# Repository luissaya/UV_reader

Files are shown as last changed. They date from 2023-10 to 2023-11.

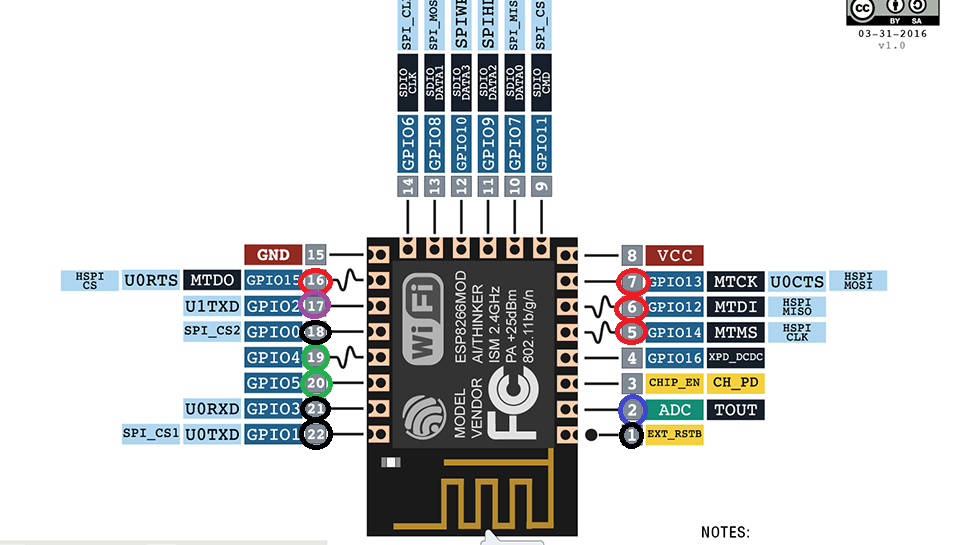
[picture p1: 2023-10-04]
img/pinout-esp8266.png

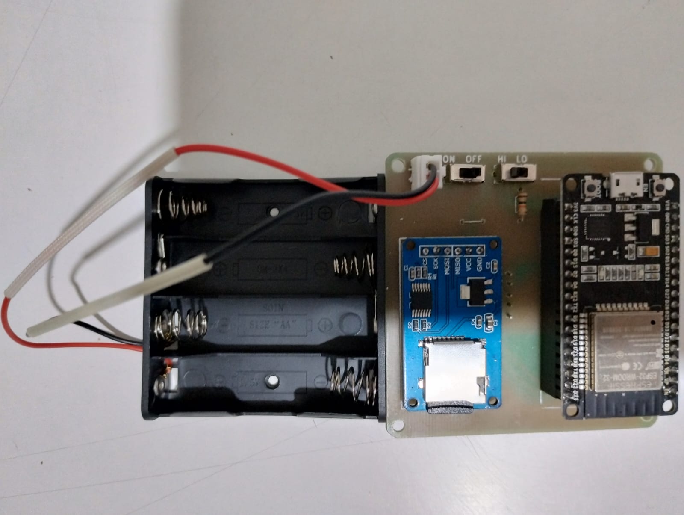
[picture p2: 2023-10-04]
img/pcb_front_view.jpg

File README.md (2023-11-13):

# UV reader

Read UV-A and UV-B radiation each minute and save the values with timestamp on an micro SD card.

## Pins

| Pin # | Name | Pin name | Description |
| ----- | --- | --- | --- |
| 1 | RST | - | Reset the chip |
| 2 | ADC | A0 | Read the UV sensor |
| 3 | RESET | - | Enable, must be HIGH |
| 4 | Deepsleep | 16 | Deepsleep, connect to RST pin |
| 5 | CSK | 14 | SPI pin |
| 6 | MISO | 12 | SPI pin |
| 7 | MOSI | 13 | SPI pin |
| 16 | CS | 15 | SPI pin |
| 17 | LED | 2 | LED, turn on in LOW |
| 18 | BOOT | 0 | To flash the firmware |
| 19 | SDA | 4 | I2C pin |
| 20 | SCL | 5 | I2C pin |
| 21 | RX | - | UART pin |
| 22 | TX | - | UART pin |
  
| Label | GPIO | Input | Output | Notes |
| ----- | --- | --- | --- | --- |
| D0 | GPIO16 | no interrupt  | no PWM or I2C support | HIGH at boot used to wake up from deep sleep |
| D1 | GPIO5  | OK | OK | often used as SCL (I2C) |
| D2 | GPIO4  | OK | OK | often used as SDA (I2C) |
| D3 | GPIO0  | pulled up | OK | connected to FLASH button, boot fails if pulled LOW |
| D4 | GPIO2  | pulled up | OK | HIGH at bootconnected to on-board LED, boot fails if pulled LOW |
| D5 | GPIO14 | OK | OK | SPI (SCLK) |
| D6 | GPIO12 | OK | OK | SPI (MISO) |
| D7 | GPIO13 | OK | OK | SPI (MOSI) |
| D8 | GPIO15 | pulled to GND | OK | SPI (CS), Boot fails if pulled HIGH |
| RX | GPIO3  | OK | RX pin | HIGH at boot |
| TX | GPIO1  | TX pin | OK | HIGH at boot, debug output at boot, boot fails if pulled LOW |
| A0 | ADC0 | Analog | Input | X |

## Calibration

Calculus to obtain the reference voltaje for genering UV intensity:

- `Vref` is the reference value to obtain:
- `Vout`: is read with multimeter.
- `Nread`: is read with ADC.

```bash
Vref = Vout x 1023 / Nread
Vref = 3.684
```

In the main code, put the next expression:  

```bash
Vout = Vref x Nread / 1023
Vout = 3.684 x Nread / 1023
```

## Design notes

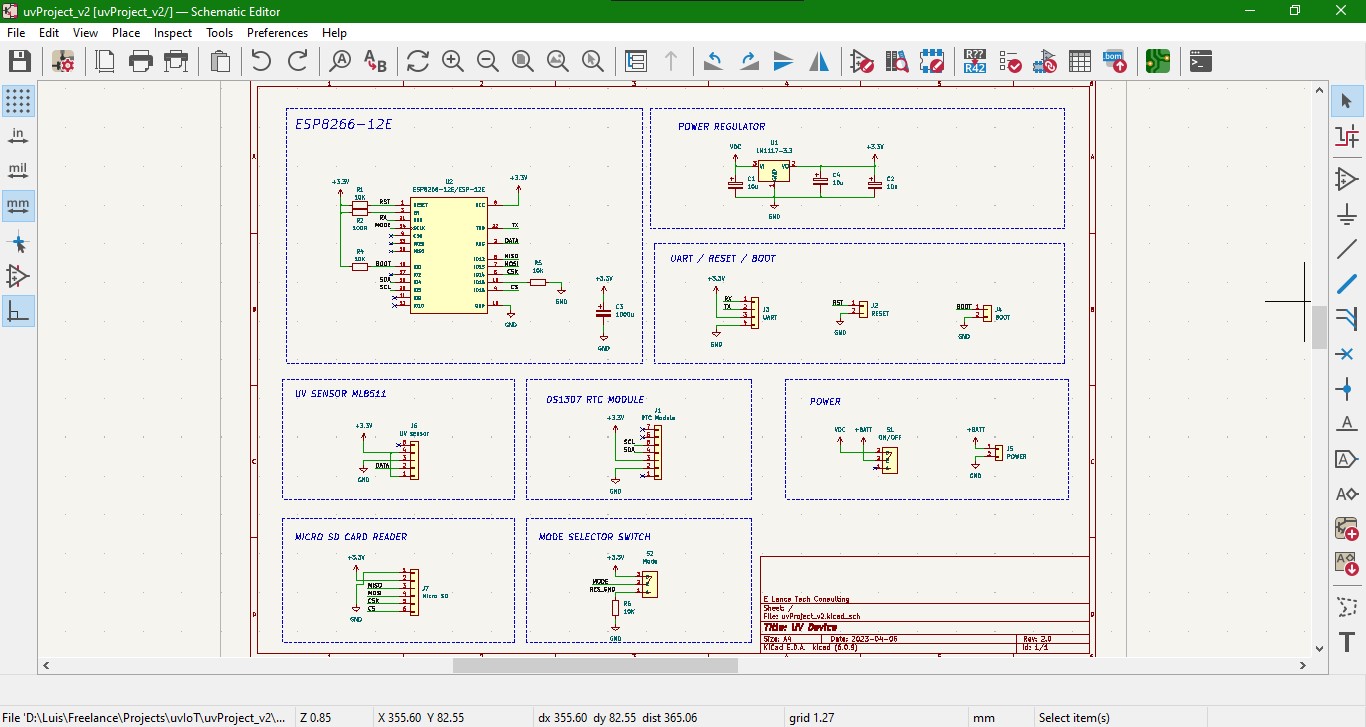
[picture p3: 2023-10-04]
img/schematic.jpg

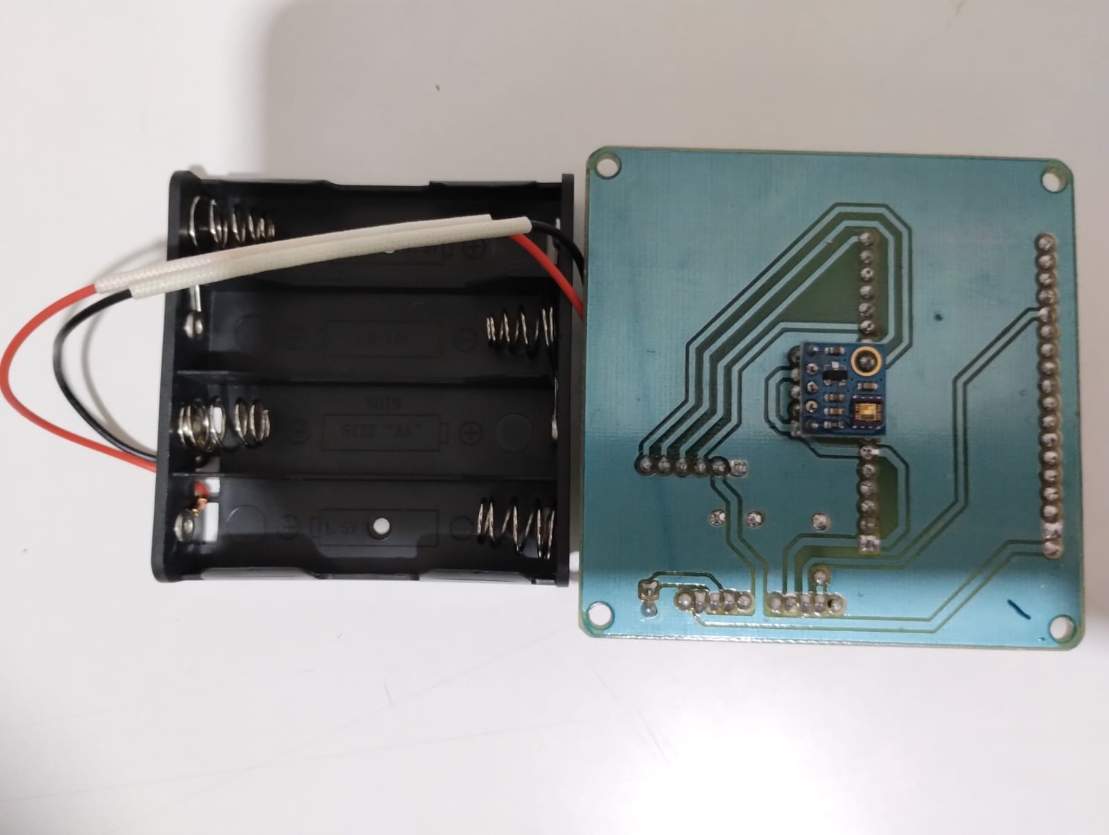
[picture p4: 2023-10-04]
img/pcb_back_view.jpg

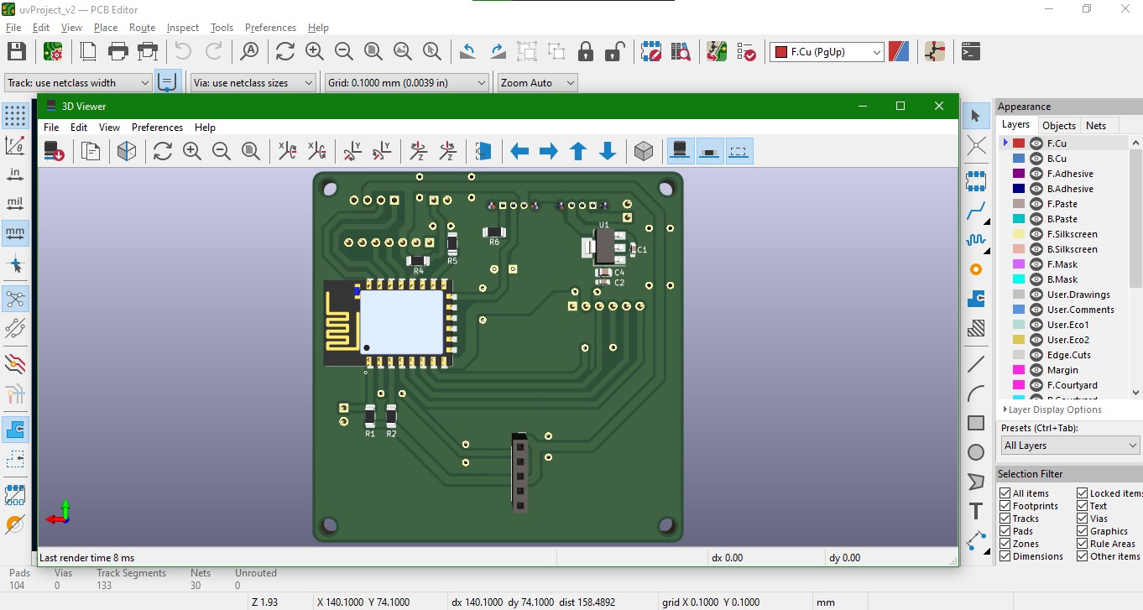
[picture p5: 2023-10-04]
img/layout.jpg

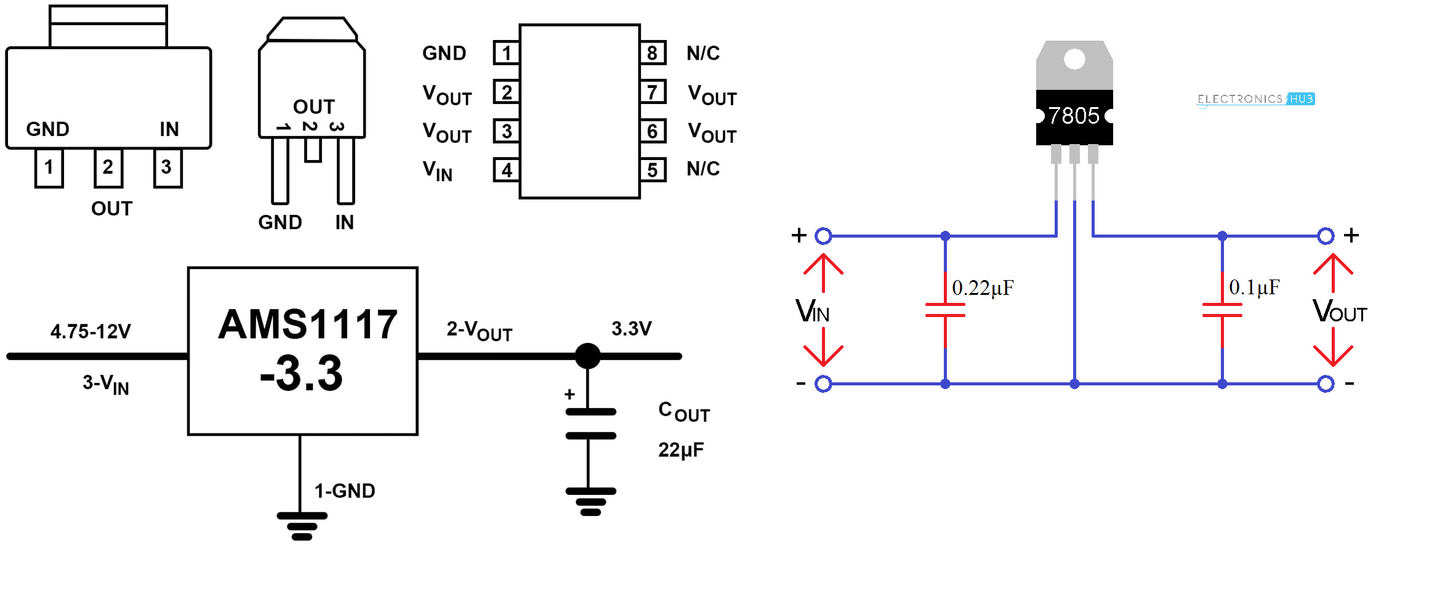
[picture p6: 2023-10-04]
pcb/uvProject_v2/crcuit.png

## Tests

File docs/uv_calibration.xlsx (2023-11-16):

Vmultimeter(volts) | Nread | Resolution | Vref(volts)
1.05 | 292 | 1023 | 3.67859589

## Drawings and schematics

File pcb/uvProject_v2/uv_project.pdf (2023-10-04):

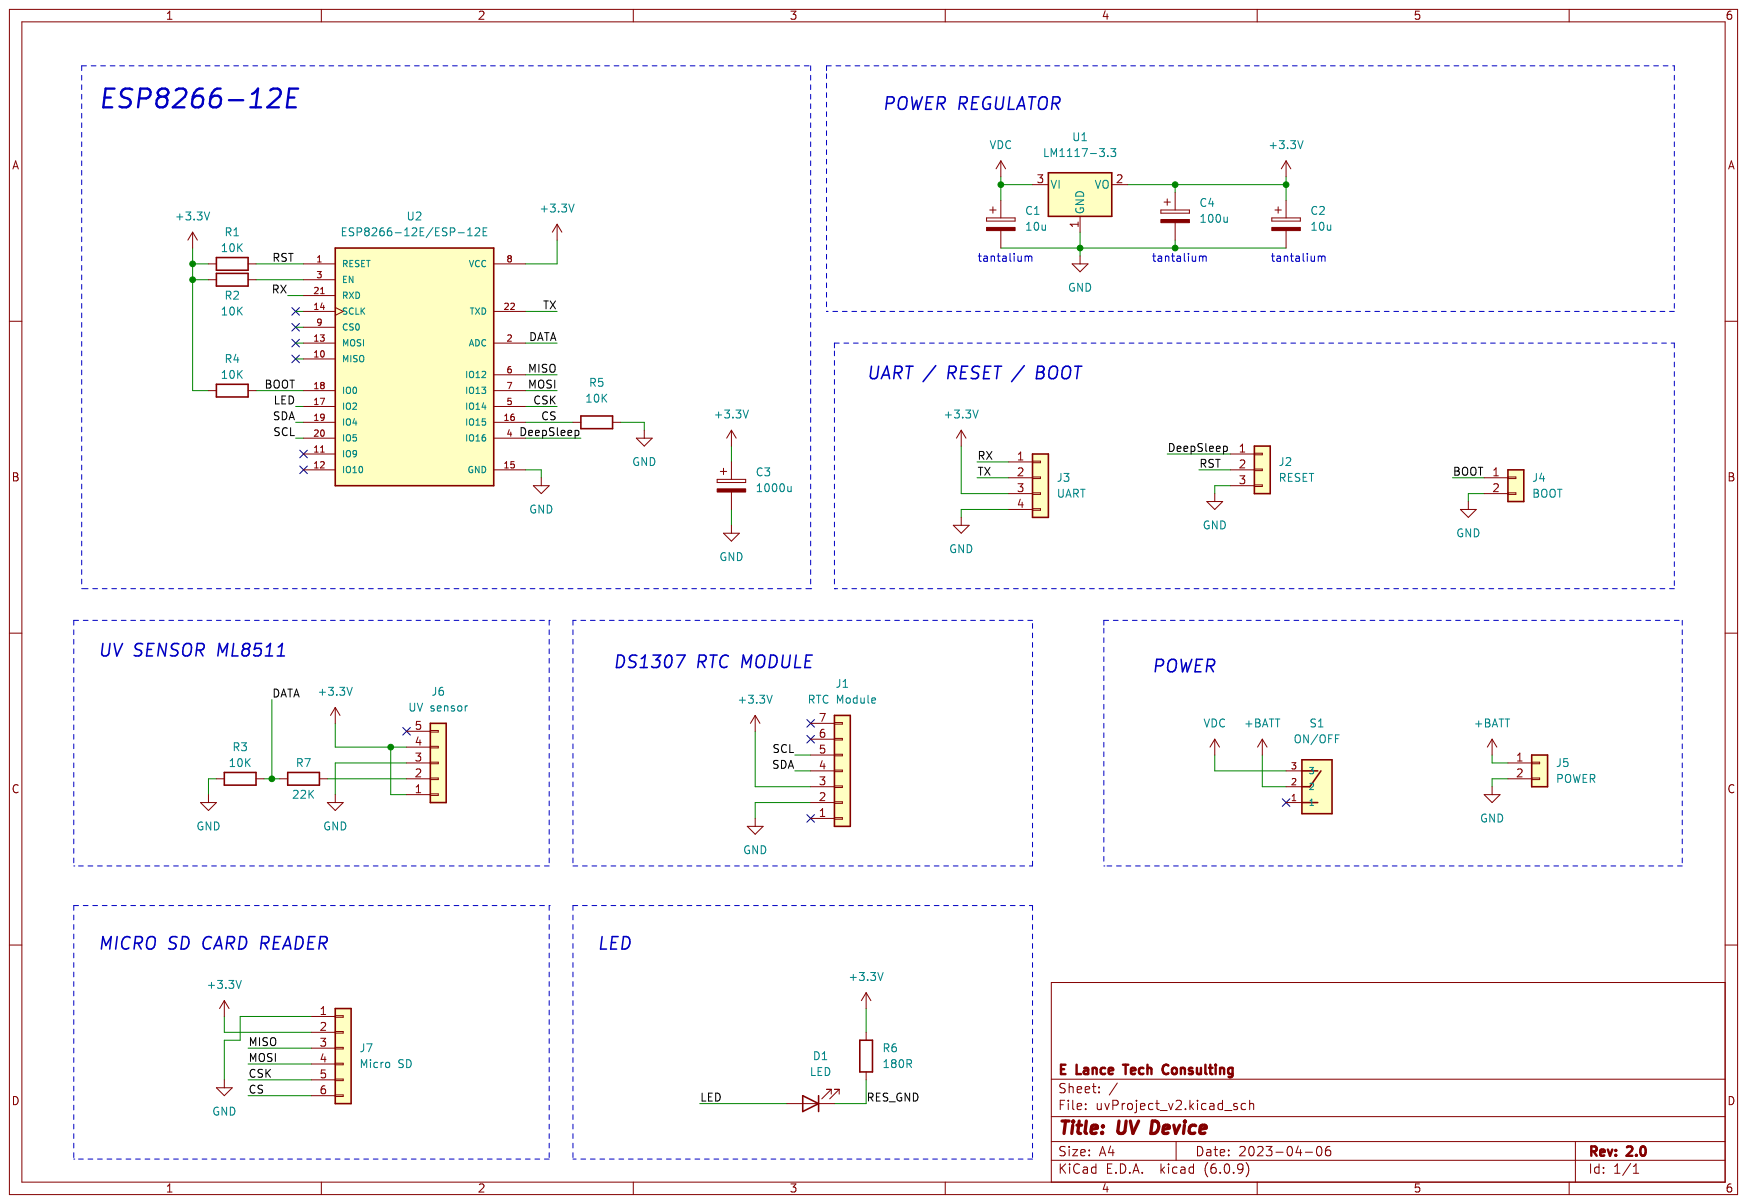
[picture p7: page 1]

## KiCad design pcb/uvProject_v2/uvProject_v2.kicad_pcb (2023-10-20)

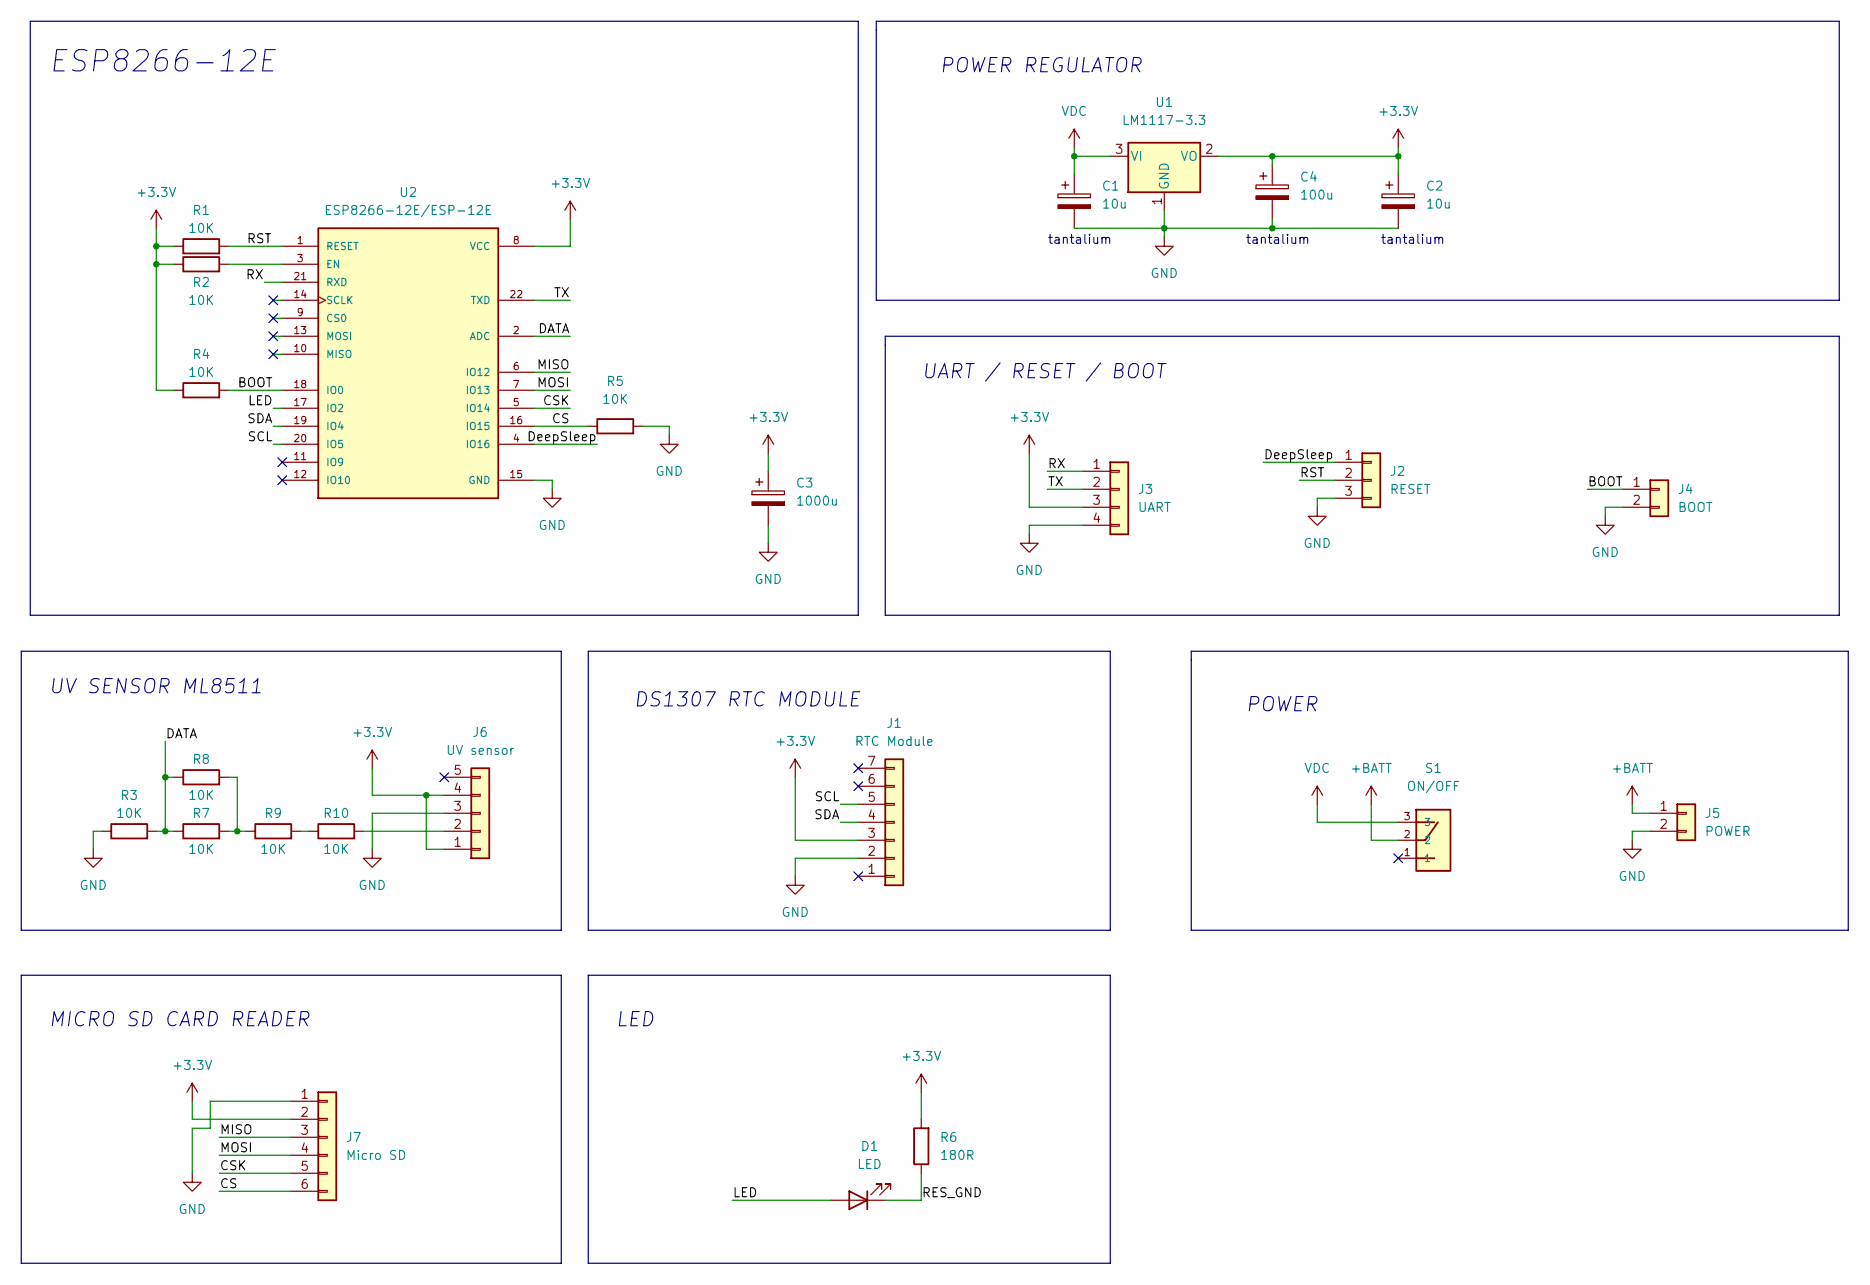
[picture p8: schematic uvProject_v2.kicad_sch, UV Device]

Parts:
C1, C2: 10u; C_0603_1608Metric_Pad1.08x0.95mm_HandSolder
C3: 1000u; CP_Radial_D8.0mm_P3.50mm
C4: 100u; C_0805_2012Metric_Pad1.18x1.45mm_HandSolder
D1: LED; LED_D3.0mm
J1: RTC Module; PinHeader_1x07_P2.54mm_Vertical
J2: RESET; PinHeader_1x03_P2.54mm_Vertical
J3: UART; PinSocket_1x04_P2.54mm_Vertical
J4: BOOT; PinHeader_1x02_P2.54mm_Vertical
J5: POWER; PinHeader_1x02_P2.54mm_Vertical
J6: UV sensor; PinSocket_1x05_P2.54mm_Vertical
J7: Micro SD; PinHeader_1x06_P2.54mm_Vertical
R1, R2, R3, R4, R5, R7, R8, R9, R10: 10K; R_1206_3216Metric_Pad1.30x1.75mm_HandSolder
R6: 180R; R_1206_3216Metric_Pad1.30x1.75mm_HandSolder
S1: ON/OFF; SW_OS102011MS2QN1
U1: LM1117-3.3; SOT-223-3_TabPin2
U2: ESP8266-12E/ESP-12E; XCVR_ESP8266-12E_ESP-12E

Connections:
+3.3V: C2.1, C3.1, C4.1, J1.3, J3.3, J6.1, J6.4, J7.2, R1.1, R2.1, R4.1, R6.2, U1.2 (VO), U2.8 (VCC)
+BATT: J5.1, S1.2
/BOOT: J4.1, R4.2, U2.18 (IO0)
/CS: J7.6, R5.1, U2.16 (IO15)
/CSK: J7.5, U2.5 (IO14)
/DATA: R3.2, R7.1, R8.1, U2.2 (ADC)
/DeepSleep: J2.1, U2.4 (IO16)
/LED: D1.2 (A), U2.17 (IO2)
/MISO: J7.3, U2.6 (IO12)
/MOSI: J7.4, U2.7 (IO13)
/RES_GND: D1.1 (K), R6.1
/RST: J2.2, R1.2, U2.1 (RESET)
/RX: J3.1, U2.21 (RXD)
/SCL: J1.5, U2.20 (IO5)
/SDA: J1.4, U2.19 (IO4)
/TX: J3.2, U2.22 (TXD)
GND: C1.2, C2.2, C3.2, C4.2, J1.2, J2.3, J3.4, J4.2, J5.2, J6.3, J7.1, R3.1, R5.2, U1.1 (GND), U2.15 (GND)
unnamed: J6.2, R10.2
unnamed: R7.2, R8.2, R9.1
unnamed: R9.2, R10.1
unnamed: R2.2, U2.3 (EN)
VDC: C1.1, S1.3, U1.3 (VI)

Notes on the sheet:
tantalium
UV SENSOR ML8511
ESP8266-12E
POWER
MICRO SD CARD READER
DS1307 RTC MODULE
LED
UART / RESET / BOOT
POWER REGULATOR

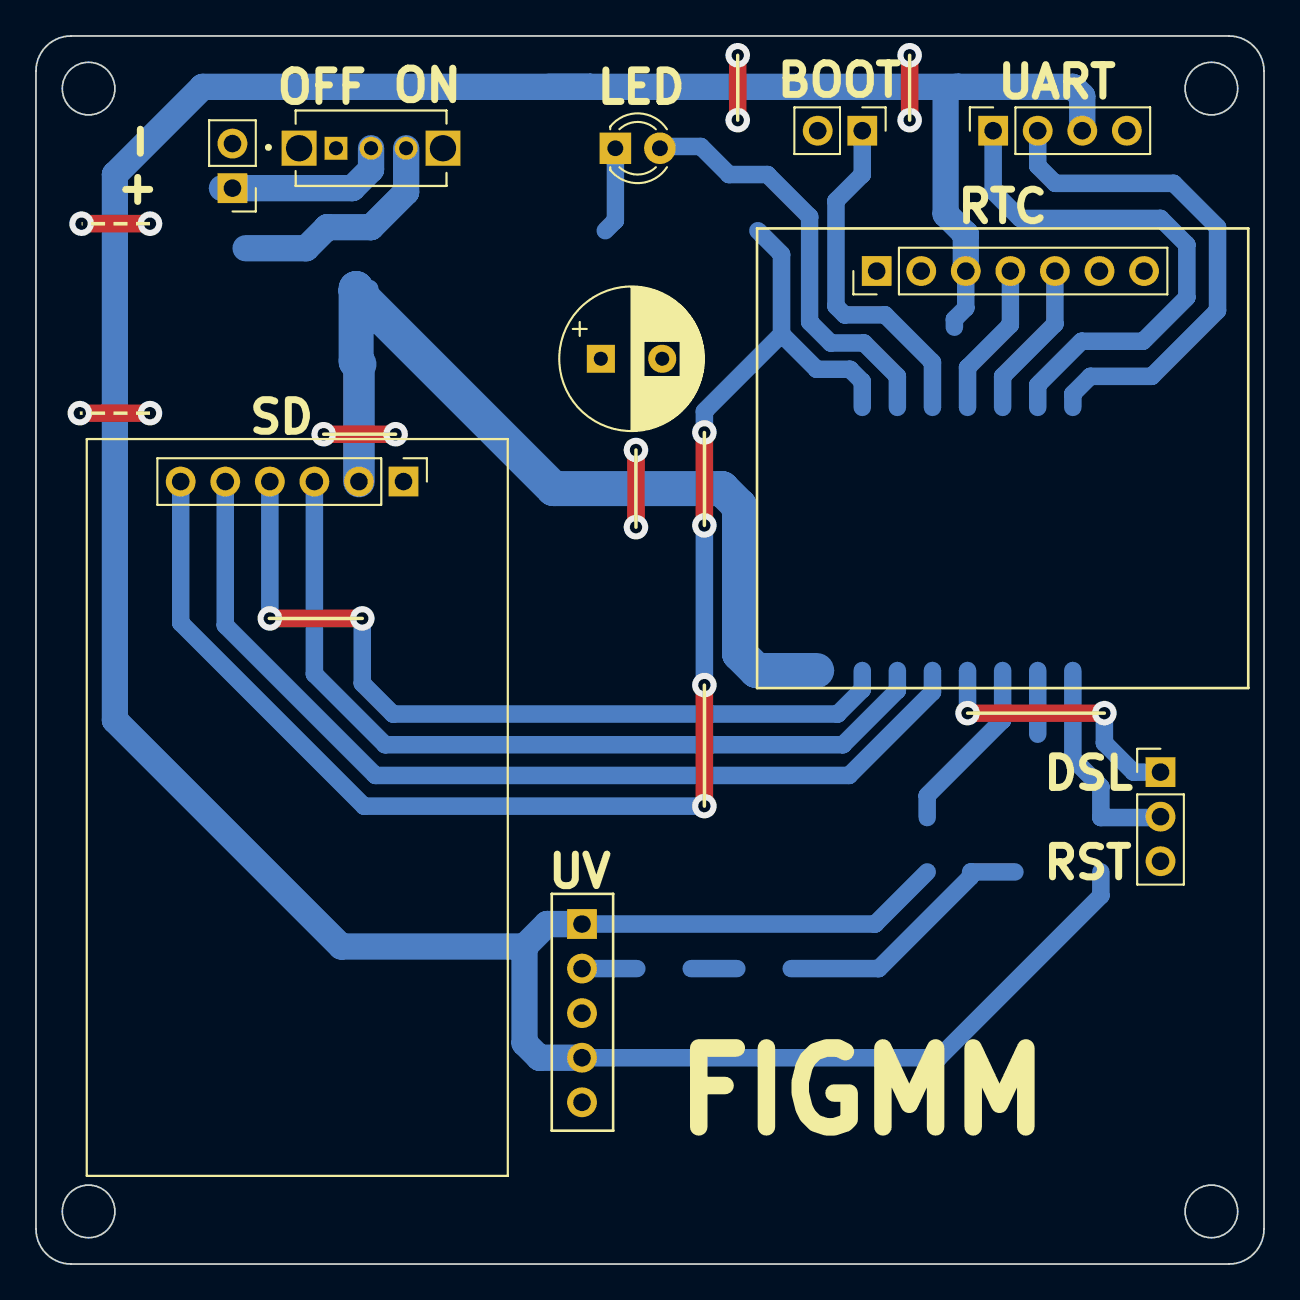
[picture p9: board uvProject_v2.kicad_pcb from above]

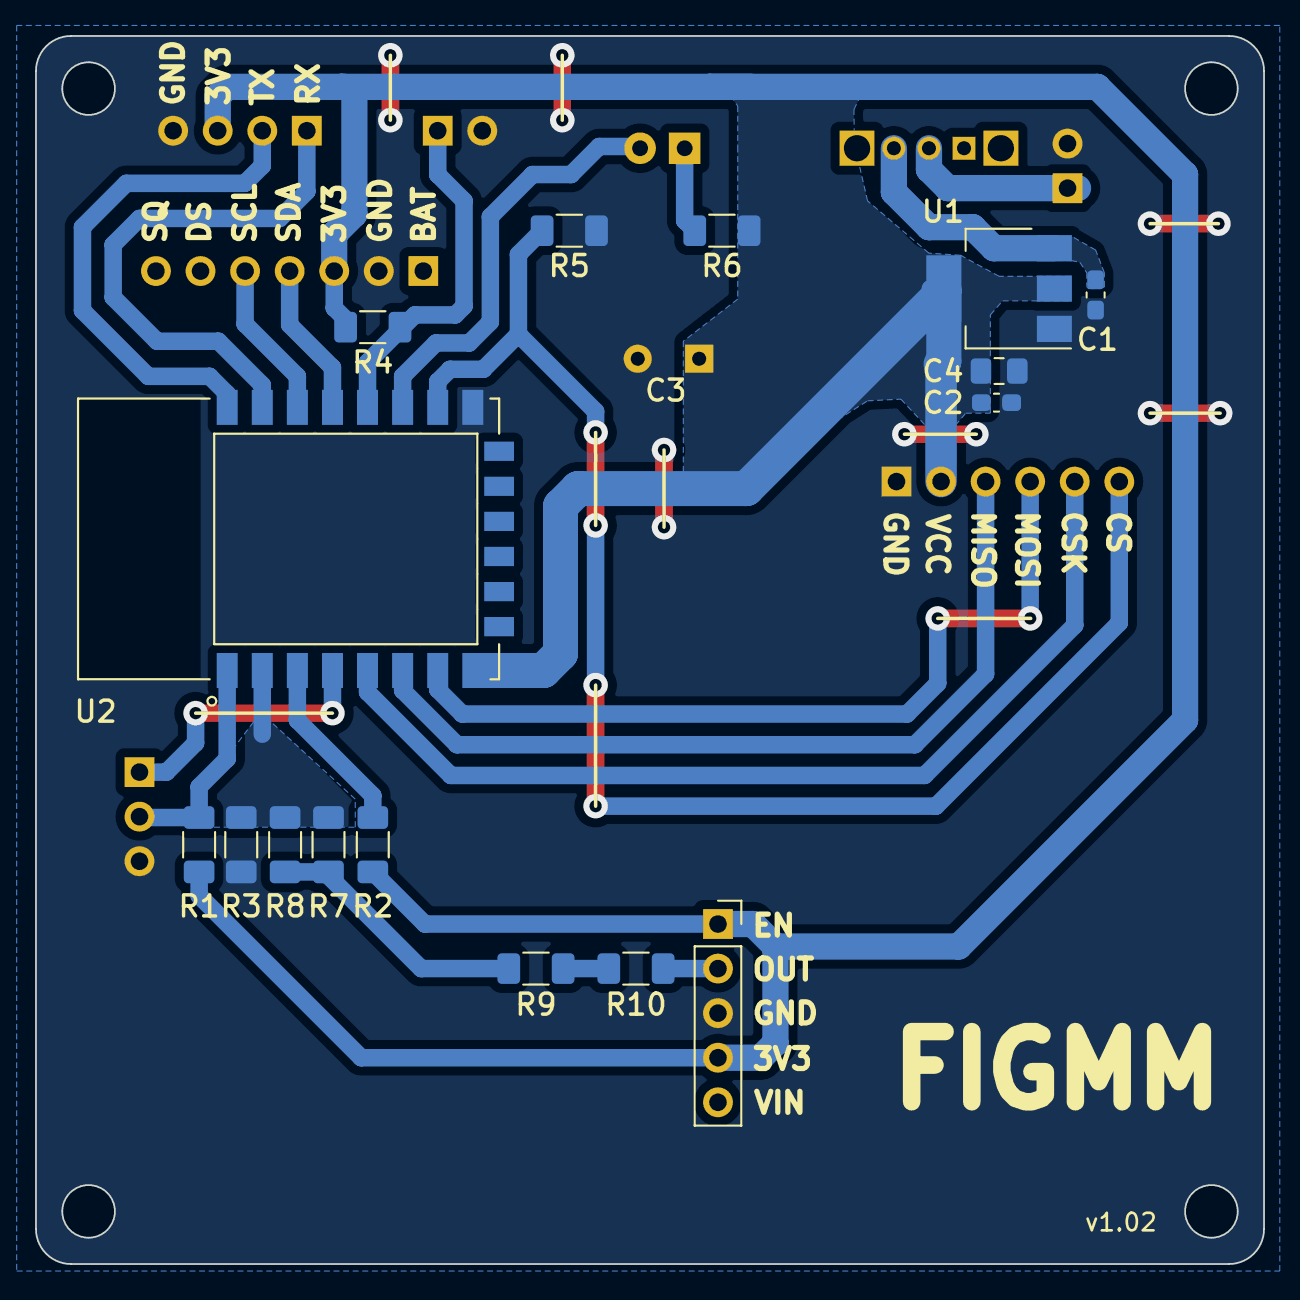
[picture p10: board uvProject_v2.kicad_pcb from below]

Board: 2 copper layers, 70.0 x 70.0 mm, 25 parts (16 on the bottom side), 22 nets.

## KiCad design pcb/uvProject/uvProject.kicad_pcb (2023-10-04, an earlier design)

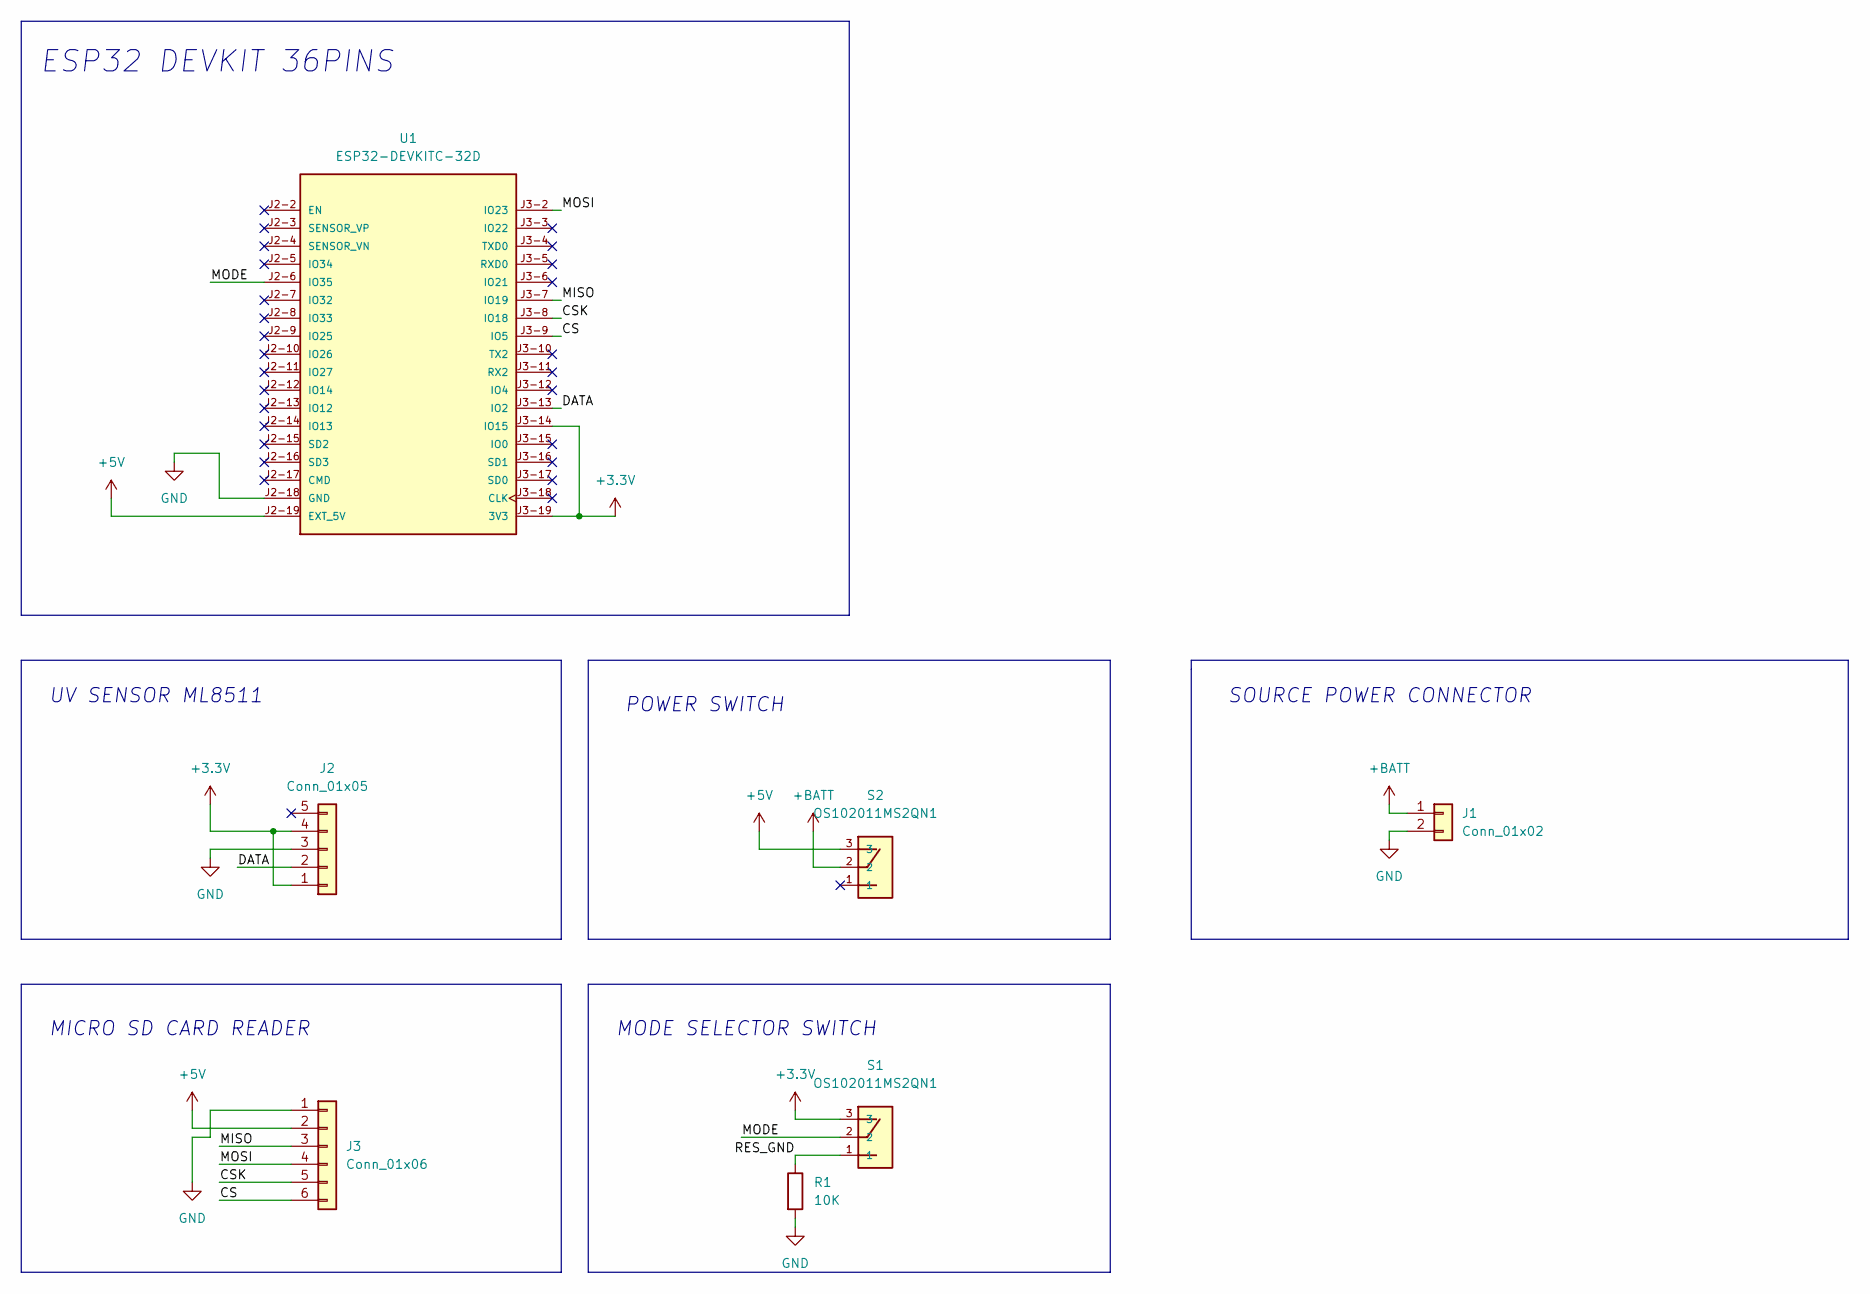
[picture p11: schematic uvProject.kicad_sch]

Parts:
J1: Conn_01x02; PinHeader_1x02_P2.54mm_Vertical
J2: Conn_01x05; PinSocket_1x05_P2.54mm_Vertical
J3: Conn_01x06; PinSocket_1x06_P2.54mm_Vertical
R1: 10K; R_Axial_DIN0204_L3.6mm_D1.6mm_P7.62mm_Horizontal
S1, S2: OS102011MS2QN1; SW_OS102011MS2QN1
U1: ESP32-DEVKITC-32D; MODULE_ESP32-DEVKITC-32D; PARTREV V4

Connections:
+3.3V: J2.1, J2.4, S1.3, U1.J3-14 (IO15), U1.J3-19 (3V3)
+5V: J3.2, S2.3, U1.J2-19 (EXT_5V)
+BATT: J1.1, S2.2
/CS: J3.6, U1.J3-9 (IO5)
/CSK: J3.5, U1.J3-8 (IO18)
/DATA: J2.2, U1.J3-13 (IO2)
/MISO: J3.3, U1.J3-7 (IO19)
/MODE: S1.2, U1.J2-6 (IO35)
/MOSI: J3.4, U1.J3-2 (IO23)
/RES_GND: R1.1, S1.1
GND: J1.2, J2.3, J3.1, R1.2, U1.J2-18 (GND)

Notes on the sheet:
ESP32 DEVKIT 36PINS
MODE SELECTOR SWITCH
POWER SWITCH
SOURCE POWER CONNECTOR
UV SENSOR ML8511
MICRO SD CARD READER

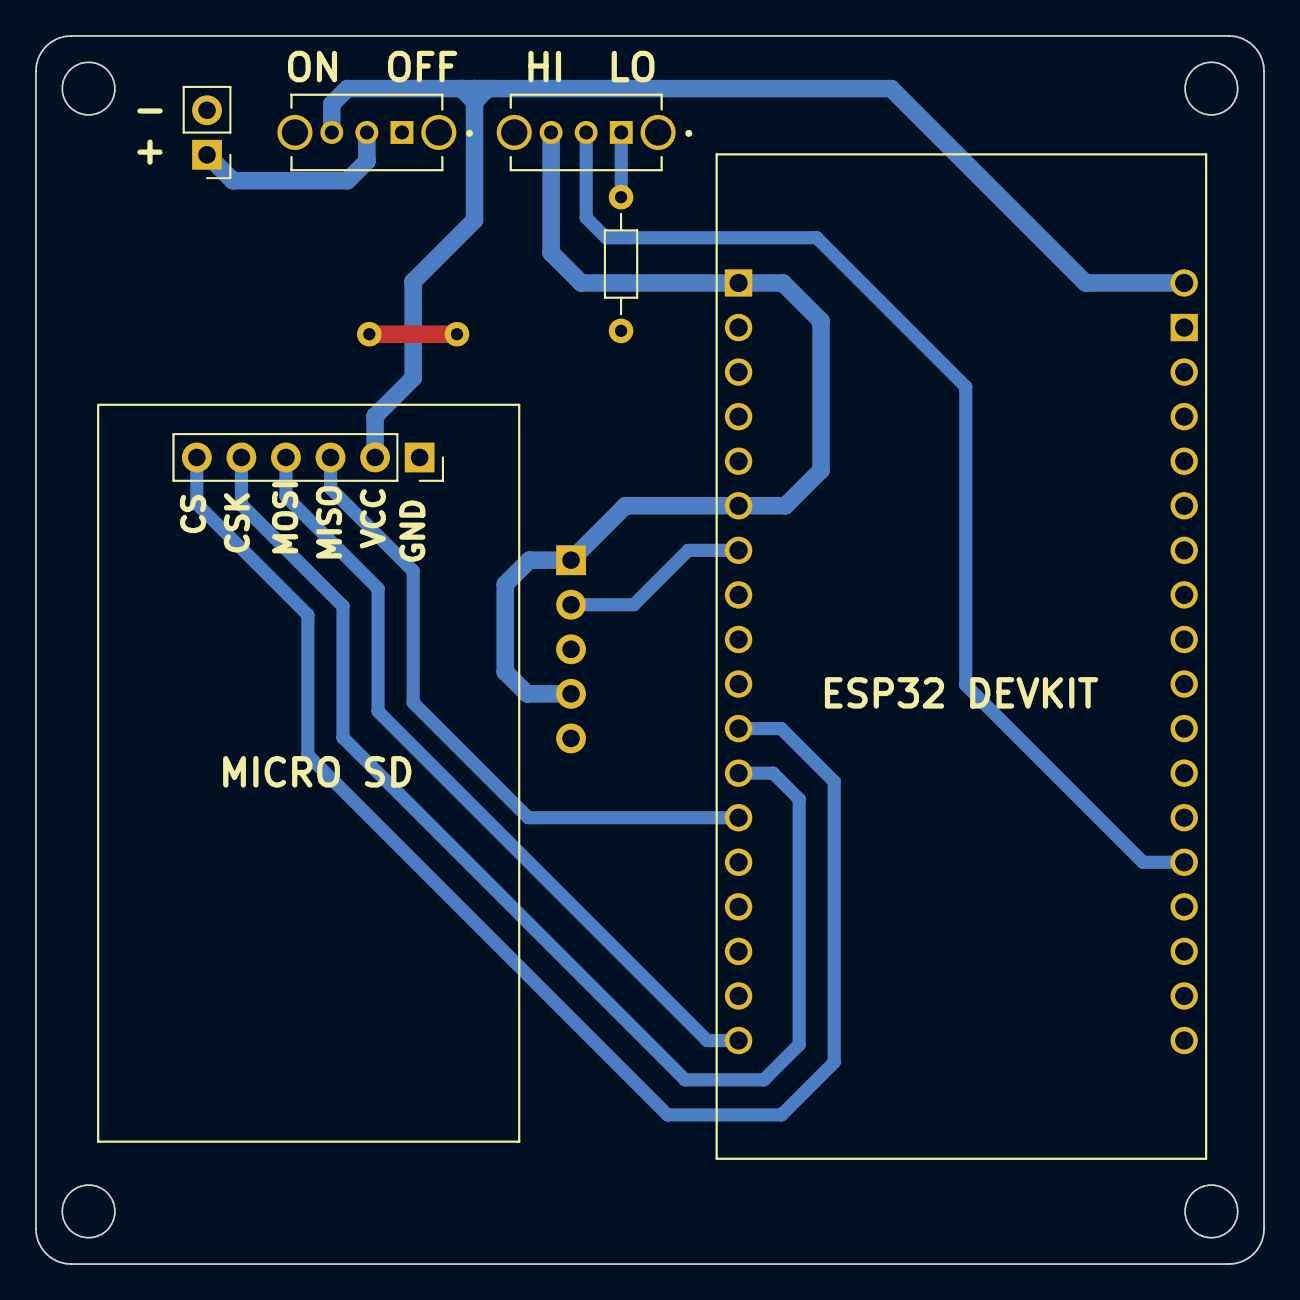
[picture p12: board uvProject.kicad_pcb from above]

Board: 2 copper layers, 70.0 x 70.0 mm, 7 parts (1 on the bottom side), 11 nets.

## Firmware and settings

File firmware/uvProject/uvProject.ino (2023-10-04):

#include "FS.h"
#include "SD.h"
#include "SPI.h"

#define SCK  18
#define MISO 19
#define MOSI 23
#define CS    5
#define UVOUT 2 //Output from the sensor
#define REF  15 //3.3V power on the ESP32 board
#define MODE 35 //Output from the operation mode

#define uS_TO_S_FACTOR 1000000  /* Conversion factor for micro seconds to seconds */
#define Sleep_Interval 10000 //10 seconds
#define time_HI 30
#define time_LO 60
#define led 2
/* create a hardware timer */
hw_timer_t * timer = NULL;
unsigned long previousMillis = 0; 

String nameFILE = "/uvData.csv"; // .csv file
float uvLevel = 0.0;
float refLevel = 0.0;
bool existName = false;
bool debug = false;
int TIME_TO_SLEEP = time_LO;        /* Time ESP32 will go to sleep (in seconds) */
int modeValue = 0;
RTC_DATA_ATTR int bootCount = 0;


void averageRead(int numberReadings);
float voltageToIntensity(float voltage);
void writeFile(fs::FS &fs, String name, String message);
void addData(fs::FS &fs, String name, float message);
void createFileTitle(fs::FS &fs, String name, String message);

SPIClass sdspi(VSPI);

volatile byte state = LOW;

void IRAM_ATTR onTimer(){
  state = !state;
  digitalWrite(led, state);
}

void setup(){
  if(debug) Serial.begin(115200);
  if(debug) delay(2000);    
  if(debug) Serial.println("Initializing");  
  pinMode(UVOUT, INPUT);
  pinMode(REF, INPUT);  
  pinMode(MODE, INPUT);
  pinMode(led, OUTPUT);

  modeValue = digitalRead(MODE);
  delay(50);
  if(modeValue == HIGH){
    TIME_TO_SLEEP = time_HI; // HIGH or LOW,  less time if it is activated
  }

  /* Use 1st timer of 4 */
  /* 1 tick take 1/(80MHZ/80) = 1us so we set divider 80 and count up */
  timer = timerBegin(0, 80, true);
  /* Attach onTimer function to our timer */
  timerAttachInterrupt(timer, &onTimer, true);
  /* Set alarm to call onTimer function every second 1 tick is 1us
  => 1 second is 1000000us */
  /* Repeat the alarm (third parameter) */
  timerAlarmWrite(timer, 0.2*uS_TO_S_FACTOR, true);
  timerAlarmEnable(timer);

  //boot count
  ++bootCount;
  if(debug) Serial.println("Boot number: " + String(bootCount));

  sdspi.begin(SCK, MISO, MOSI, CS);

  while(!SD.begin(CS,sdspi)){
    if(debug) Serial.println("Card Mount Failed");
    unsigned long currentMillis = millis();
    Serial.println(currentMillis);
    if (currentMillis >= Sleep_Interval) {
      if(debug) Serial.println("Setup ESP32 to sleep for every indefinitely");
      //esp_sleep_enable_timer_wakeup(120*uS_TO_S_FACTOR);
      esp_sleep_enable_touchpad_wakeup();
      esp_deep_sleep_start();
    }
  }
  if(debug) Serial.println("Card Mount successfully");
  uint8_t cardType = SD.cardType();

  while(cardType == CARD_NONE){
    if(debug) Serial.println("No SD card attached");
    unsigned long currentMillis = millis();
    if (currentMillis - previousMillis >= Sleep_Interval) {
      if(debug) Serial.println("Setup ESP32 to sleep for every indefinitely");
      //esp_sleep_enable_timer_wakeup(120*uS_TO_S_FACTOR);
      esp_sleep_enable_touchpad_wakeup();
      esp_deep_sleep_start();
    }
    delay(500);
  }
  if(debug) Serial.println("SD card attached successfully");

  // if(!SD.begin(CS,sdspi)){
  //   if(debug) Serial.println("Card Mount Failed");
  //   return;
  // }
  // uint8_t cardType = SD.cardType();
  // if(cardType == CARD_NONE){
  //   if(debug) Serial.println("No SD card attached");
  //   return;
  // }
  if(bootCount == 1){
    createFileTitle(SD,nameFILE, "Time, UV Intensity (mW/cm^2)\n");
    delay(1000);
  }
  timerAlarmDisable(timer);
  digitalWrite(led, LOW);

  float uvIntensity = voltageToIntensity(averageVoltage(20)); //Convert the voltage to a UV intensity level
  String timepass = timeElapsed(bootCount-1);
  if(debug) Serial.println(timepass);
  addData(SD, nameFILE, timepass + ", " + String(uvIntensity));
  //go to sleep
  esp_sleep_enable_timer_wakeup(TIME_TO_SLEEP * uS_TO_S_FACTOR);
  if(debug) Serial.println("Setup ESP32 to sleep for every " + String(TIME_TO_SLEEP) +" Seconds");
  if(debug) Serial.print("ESP is going to sleep");
  Serial.flush(); 
  esp_deep_sleep_start();
}

void loop(){
  //This is not going to be called
}

float averageVoltage(int numberReadings){ 
  for(int x = 0 ; x < numberReadings ; x++)
  {
    uvLevel += analogRead(UVOUT);
    refLevel += analogRead(REF);
  }
  uvLevel /= (float)numberReadings;
  refLevel /= (float)numberReadings;
  //Use the 3.3V power pin as a reference to get a very accurate output value from sensor
  return (3.3 / refLevel * uvLevel);
}

float voltageToIntensity(float voltage){
  float in_min = 0.99;
  float in_max = 2.8;
  float out_min = 0.0;
  float out_max = 15.0;
  if (voltage <= in_min){
    return out_min;
  }
  return (voltage - in_min) * (out_max - out_min) / (in_max - in_min) + out_min;
}

void addData(fs::FS &fs, String name, String message){
 if(debug) Serial.print("Appending to file: "+ name);

  File file = fs.open(name, FILE_APPEND);
  if(!file){
    if(debug) Serial.println(" Failed to open file for appending");
    return;
  }
  if(file.println(message)){
     if(debug) Serial.println(" Message appended");
  } else {
    if(debug) Serial.println(" Append failed");
  }
  file.close();
}

void createFileTitle(fs::FS &fs, String name, String message){
 if(debug) Serial.print("Appending to file: "+ name);

  File file = fs.open(name, FILE_APPEND);
  if(!file){
    if(debug) Serial.println(" Failed to open file for appending");
    return;
  }
  if(file.print(message)){
    if(debug) Serial.println(" Title appended");
  } else {
    if(debug) Serial.println(" Append failed");
  }
  file.close();
}

String timeElapsed(int boot){
  String timeDHM;
  int timeD = boot/3600;
  int timeH = (boot - timeD*3600)/60 ;
  int timeM = boot - timeD*3600 - timeH*60;
  String sTimeD;
  String sTimeH;
  String sTimeM;
  if (timeD<10){
      sTimeD = "0"+String(timeH);
    }else {
      sTimeD = String(timeH);
    }
   if (timeH<10){
      sTimeH = "0"+String(timeH);
    }else {
      sTimeH = String(timeH);
    }
   if (timeM<10){
      sTimeM = "0"+String(timeM);
    }else {
      sTimeM = String(timeM);
    }
  timeDHM = sTimeD+"D:"+sTimeH+"H:"+sTimeM+"M";
  return timeDHM;
}

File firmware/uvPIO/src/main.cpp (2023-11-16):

/*
Repository: https://github.com/luissaya/UV_reader
Project: UV radiation data collector
Author: Luis Sayaverde Bravo
v1.04
*/
#include <SPI.h>
#include <SD.h>
#include <Ticker.h>
#include "RTClib.h"
/*
ESP12E 
- I2C:  SDA=GPIO4, 
        SCL=GPIO5
- SPI:  MISO=GPIO12, 
        MOSI=GPIO13, 
        CSK=GPIO14 
        CS=GPIO15 <> D8
- LED:  GPIO2 <> D4
- ADC:  A0
*/

// CONSTANTS //
#define CS  D8 //GPIO15 D8 
#define LED D4 //GPIO2 D4
#define UV  A0 // A0
#define sleep_waiting 10e3 //time for sleep indefinitely if there is an error
#define sleep_time 60e6 //time for take each measurement
bool debug = false; //true to activate debug prints
String title = "uvData.csv";//csv file name
String fileHeader = "Fecha(DD/MM/AAAA), Hora(HH:MM:SS), UV Intensity(mW/cm^2)";//header of csv file
float RES = 1023.0;//ADC resolution
float REF = 3.684;//variable obtained through calibration

// VARIABLES //
unsigned long previousMillis = 0; 
String message = "";
float uvIntensity = 0.0;

// INSTANCES //
File myFile;
Ticker blinker;
RTC_DS1307 rtc;

// FUNCTION PROTOTYPES //
void changeState();
float avgVoltage(int nReadings);
float voltToIntensity(float voltage);
void writingSD(String message, String file);
void readingSD(String file);
void printDirectory();
String currentTime();
String addZero(int number);

// MAIN SETUP //
void setup() {
  // Open serial communications and wait for port to open:
  if(debug) Serial.begin(9600);
  pinMode(LED,OUTPUT);
  pinMode(UV, INPUT);
  if(debug) delay(1000);
  if(debug) Serial.println("Initializing");
  blinker.attach(0.2, changeState); //Initialize Ticker every 0.5s (Use attach_ms for time in ms)
  
  while (! rtc.begin()) {
    if(debug) Serial.println("Couldn't find RTC");
    if(debug) Serial.flush();
    // ADD SLEEP
    unsigned long currentMillis = millis();
    if (currentMillis >= sleep_waiting) {
      if(debug) Serial.println("Setup to sleep for every indefinitely");
      if(debug) Serial.flush();
      ESP.deepSleep(0); 
    }
  }
  if (!rtc.isrunning()) {
    if(debug) Serial.println("RTC is NOT running, let's set the time!");
    rtc.adjust(DateTime(F(__DATE__), F(__TIME__)));
  }
/////////////////////////////////////////////////////
// rtc.adjust(DateTime(F(__DATE__), F(__TIME__)));//set the time with the compiled one
////////////////////////////////////////////////////
// rtc.adjust(DateTime(2023, 4, 9, 11, 47, 0));
  
  if(debug) Serial.print("Initializing SD card...");
  while (!SD.begin(CS)) {
    if(debug) Serial.println("initialization failed!");
    // ADD SLEEP
    unsigned long currentMillis = millis();
    if (currentMillis >= sleep_waiting) {
      if(debug) Serial.println("Setup to sleep for every indefinitely");
      if(debug) Serial.flush();
      ESP.deepSleep(0);
    }
    delay(1000);
  }
  if(debug) Serial.println("initialization done.");
  
  blinker.detach(); 
  digitalWrite(LED,HIGH);

  if (!SD.exists(title)) {
    if(debug) Serial.println(title + " doesn't exist");
    if(debug) Serial.println("File Header : " + fileHeader);
    writingSD(fileHeader, title);
  }
  if(debug) Serial.println(title + " exists");
  //Convert the voltage to a UV intensity level
  uvIntensity = voltToIntensity(avgVoltage(20));
  message = currentTime() +", "+ String(uvIntensity);
  writingSD(message, title);
  // if(debug) readingSD(title);
  if(debug) Serial.println(message);

  if(debug) Serial.println("I'm awake, but I'm going into deep sleep mode for 60 seconds");
  if(debug) Serial.flush();
  ESP.deepSleep(sleep_time);
}

// MAIN LOOP //
void loop() {
  
}

// BLINK FOR LED //
void changeState(){
  digitalWrite(LED, !(digitalRead(LED)));  //Invert Current State of LED  
}

// GET AVERAGE VOLTAGE OF UV //
float avgVoltage(int nReadings){ 
  int uvLevel = 0;
  for(int x = 0 ; x < nReadings ; x++)
  {
    uvLevel += analogRead(UV);
  }
  uvLevel /= (float)nReadings;
  //Use the 3.3V power pin as a reference to get a very accurate output value from sensor
  return (REF / RES * uvLevel);
}

// CONVERT VOLTAGE OF UV TO UV INTENSITY //
float voltToIntensity(float voltage){
  float in_min = 0.99;
  float in_max = 2.8;
  float out_min = 0.0;
  float out_max = 15.0;
  if (voltage <= in_min){
    return out_min;
  }
  return (voltage - in_min) * (out_max - out_min) / (in_max - in_min) + out_min;
}

// WRITE UV INTENSITY & DATE ON SD //
void writingSD(String message, String file){
  // open the file. note that only one file can be open at a time,
  // so you have to close this one before opening another.
  myFile = SD.open(file, FILE_WRITE);

  // if the file opened okay, write to it:
  if (myFile) {
    if(debug) Serial.println("Writing to : " + file);
    myFile.println(message);
    // close the file:
    myFile.close();
    if(debug) Serial.println("done.");
  } else {
    // if the file didn't open, print an error:
    if(debug) Serial.println("error opening : " + file);
  }
}

// READ SD DATA //
void readingSD(String file){
  // open the file for reading:
  myFile = SD.open(file);
  if (myFile) {
    Serial.println(file);

    // read from the file until there's nothing else in it:
    while (myFile.available()) {
      Serial.write(myFile.read());
    }
    // close the file:
    myFile.close();
  } else {
    // if the file didn't open, print an error:
    Serial.println("error opening : " + file);
  }
}

// GET CURRENT TIME FROM RTC //
String currentTime(){
  DateTime now = rtc.now();
  String ddmmyy = String(now.day()) +"/"+ String(now.month()) +"/"+ String(now.year());

  int hour = int(now.hour());
  int minute = int(now.minute());
  int second = int(now.second());
  String hhmmss = addZero(hour) +":"+ addZero(minute) +":"+ addZero(second);
  return ddmmyy + ", " + hhmmss;
}

// ADD ZEROS TO THE TIME //
String addZero(int number){
  if(number<10){
    return "0" + String(number);
  }
  return String(number);
}

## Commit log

2023-10-04 init: initial state
    [uvProject.kicad_pcb, uvProject.kicad_sch, uvProject_v2.kicad_pcb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]
2023-10-20 update: firmware
    [uvProject_v2.kicad_pcb]
2023-11-16 chore: calibration and firmware
    [uv_calibration.xlsx]
